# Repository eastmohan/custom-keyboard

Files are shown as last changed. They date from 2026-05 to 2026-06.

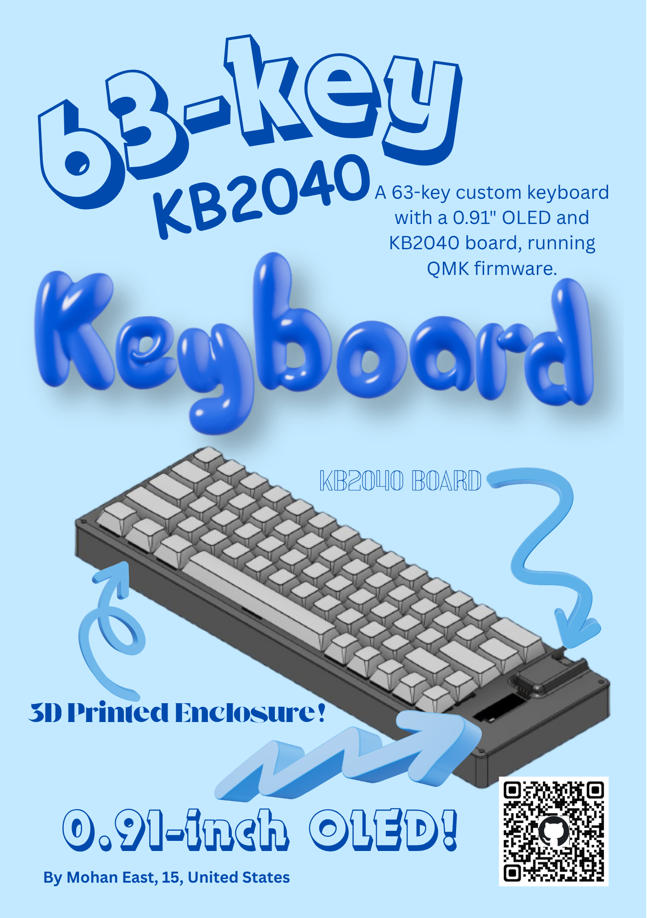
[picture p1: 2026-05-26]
zine_page.png

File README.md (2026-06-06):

# custom-keyboard
**What?** </br>
This is a custom keyboard using KB2040 board. It has 63 keys and a 0.91" OLED. See below for the key assignments. 

**Why?** </br>
I am making this because I prefer using a keyboard to work at home rather than the one built in to my computer. The only keyboard I have is an old, somewhat broken membrane keyboard so I figured I'd try to make a custom mechanical one. I previously made a custom macropad, so I thought this would be a cool next step.

NOTE: You may have noticed that there is no .f3d file in the CAD folder. Instead, there is a .f3z file. They are the same except Fusion360, which I used for the CAD, only gives the option to save as .f3z (not .f3d) when you reference other components. Those referenced components are also included in the CAD folder in the **Premade Files** folder.

**To build this project:**
- Upload gerber and drill files to PCB manufacturer website
- Order PCB and components in the BOM
- Place the switches in the PCB
- **Switches should be placed through the keyboard lid 3D print to the PCB**
- Solder switches
- Place the diodes in the PCB in the correct orientation
- Solder the diodes
- Place the microcontroller
- Solder the microcontroller pin headers to the PCB and to the microcontroller
- Place button and solder
- 3D print case and insert PCB
- Plug microcontroller into computer in boot mode, upload firmware
- Enjoy your new keyboard!

**Schematic**

**PCB**

**Case CAD**

**Key Assignments**
Key Assignments <br>
**BOM**
|Part|Source|Quantity|Cost Each|Total Cost|Link|
|---|---|---|---|---|---|
|Keycaps (Mecha Blue)|AliExpress|1|$9.38|$9.38|[Link](https://www.aliexpress.us/item/3256806811144120.html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)|
|Gateron Milky Yellow Pro 2 Switches|Amazon|1|$16.99|$16.99|[Link](https://www.amazon.com/dp/B0C2CWR4HH)|
|KB2040 Microcontroller|Adafruit|1|$8.95|$8.95|[Link](https://www.adafruit.com/product/5302)|
|USBC to USBA Cable|Amazon|1|$7.99|$7.99|[Link](https://www.amazon.com/Braided-Charging-iPhone-Samsung-Galaxy/dp/B0DPMQ7291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)|
|Diodes|Aliexpress|1|$12.53|$12.53|[Link](https://www.aliexpress.us/item/3256807937287294.html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)|
|0.91" OLED|Aliexpress|1|$2.89|$2.89|[Link](https://www.aliexpress.us/item/3256808615612857.html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)|
|M3 Heatset Insert, OD 4.2mm|Aliexpress|1|$3.60|$3.60|[Link](https://www.aliexpress.us/item/3256803396040989.html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)|
|Stabilizers|Aliexpress|1|$5.92|$5.92|[Link](https://www.aliexpress.us/item/3256801499984864.html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)|
|PCB|JLCPCB|1 (5 pack)|$17.10|$17.10|Use production files in the PCB folder of this repository.|

zine_page

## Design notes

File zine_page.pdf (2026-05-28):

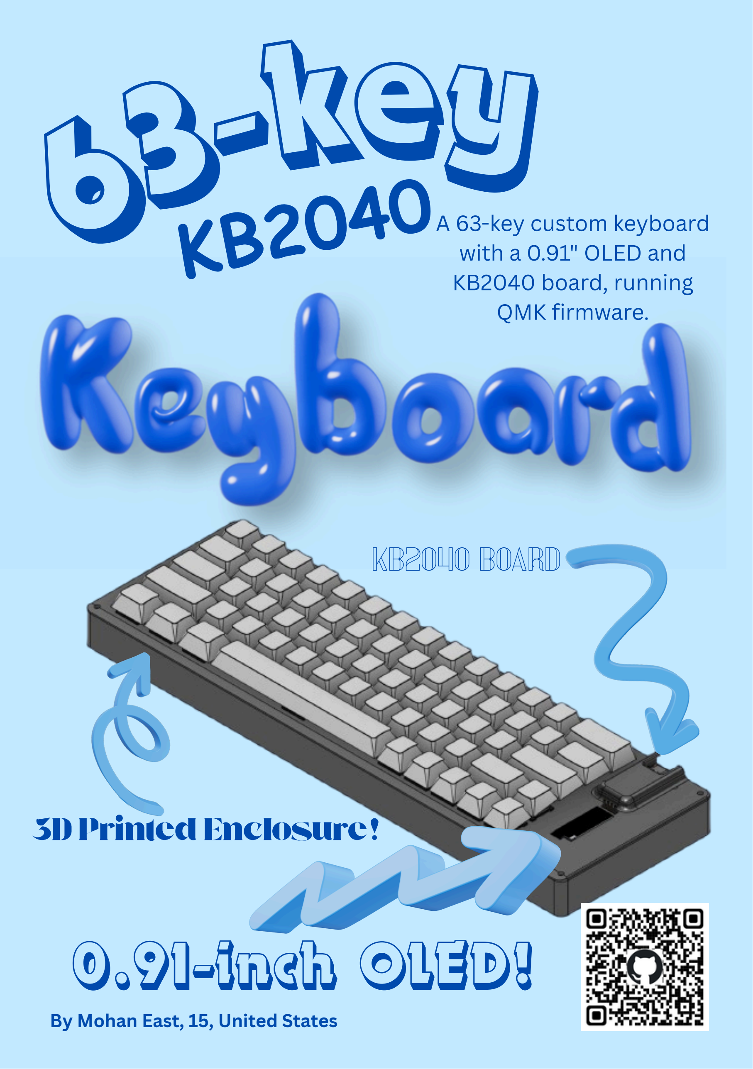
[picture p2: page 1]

# 63-key

KB2040

# 0.91-inch OLED!

KB2040 board

3D Printed Enclosure!

By Mohan East, 15, United States

A 63-key custom keyboard
with a 0.91" OLED and
KB2040 board, running
QMK firmware.

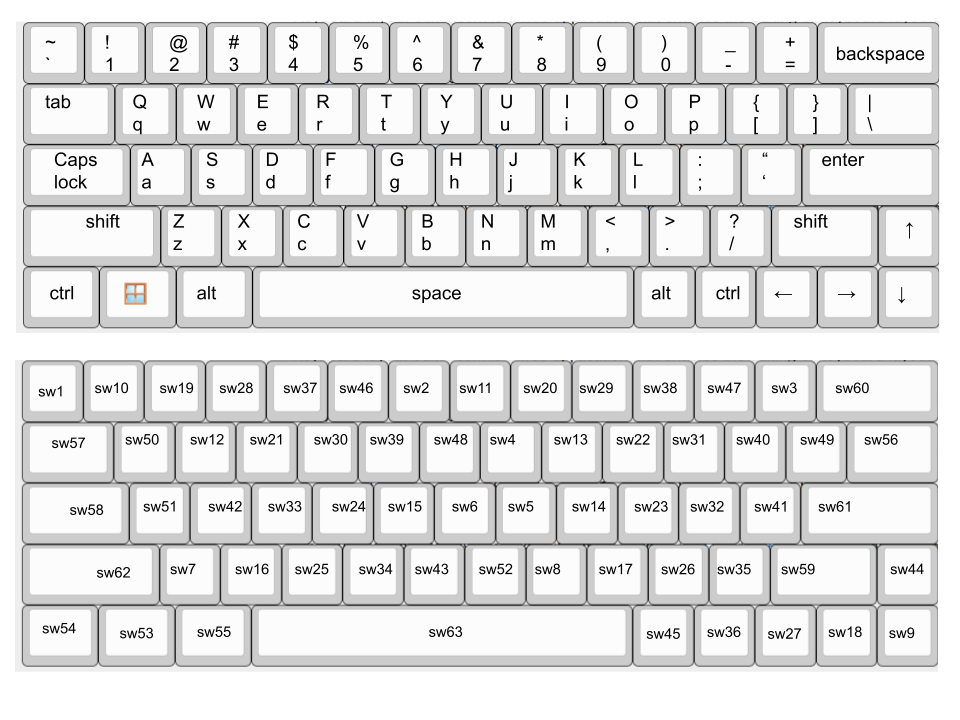
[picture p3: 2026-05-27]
Firmware/Key Assignments.png

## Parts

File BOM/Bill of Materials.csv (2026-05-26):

Part | Source | Quantity | Cost Each | Total Cost | Link
Keycaps | Keychron | 1 | $39.99 | $39.99 | https://www.keychron.com/collections/cherry-profile-double-shot-pbt-keycaps/products/iso-cherry-profile-dye-sub-pbt-full-set-keycap-set-modern-blue
Switches | Kinetic Labs | 4 | $5.04 | $20.16 | https://kineticlabs.com/switches/gateron/gateron-grayish-switches
KB2040 Microcontroller | Adafruit | 1 | $8.95 | $8.95 | https://www.adafruit.com/product/5302
USBC to USBA Cable | Amazon | 1 | $7.99 | $7.99 | https://www.amazon.com/Braided-Charging-iPhone-Samsung-Galaxy/dp/B0DPMQ7291
Diodes | AliExpress | 1 | $12.53 | $12.53 | https://www.aliexpress.us/item/3256807937287294.html?curPageLogUid=lxjO2qs5uYjp
0.91" OLED | AliExpress | 1 | $2.89 | $2.89 | https://www.aliexpress.us/item/3256808615612857.html?curPageLogUid=SMtCSefS9n5l
M3 Heatset Insert, OD 4.2mm | AliExpress | 1 | $3.60 | $3.60 | https://www.aliexpress.us/item/3256803396040989.html?curPageLogUid=5DKc8jmBy4oP
Stabilizers | AliExpress | 1 | $5.92 | $5.92 | https://www.aliexpress.us/item/3256801499984864.html?curPageLogUid=MbHZPmZU1SUn

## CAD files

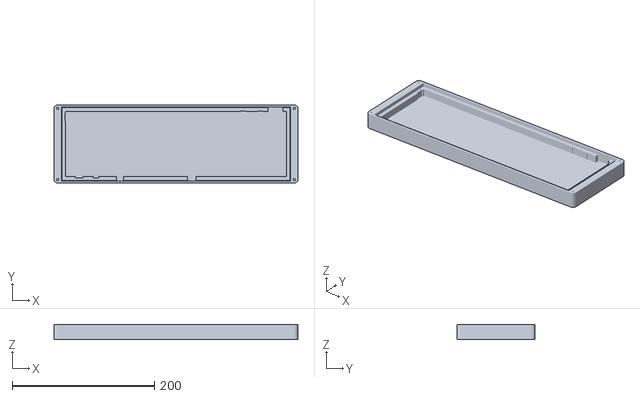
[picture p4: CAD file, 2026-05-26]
CAD/Case+bottom.stl
343.0 x 110.0 x 21.5

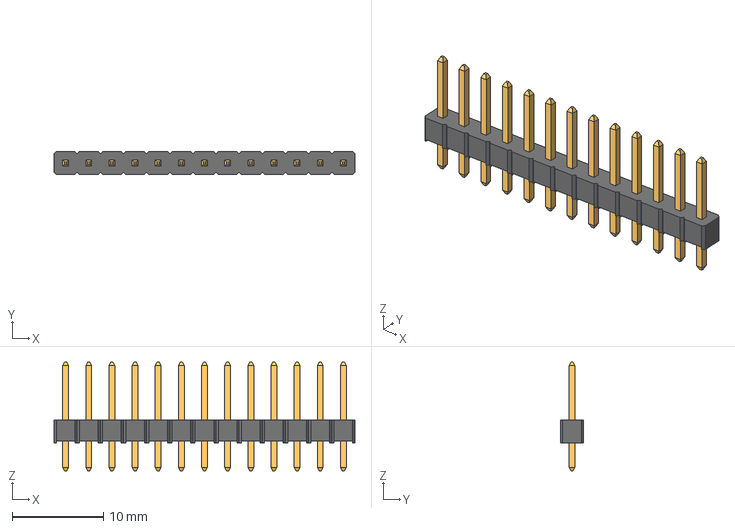
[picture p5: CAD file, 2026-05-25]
CAD/Premade Files/13-Pin Header - Male - 2.54mm.step
33.0 x 2.54 x 11.9 mm

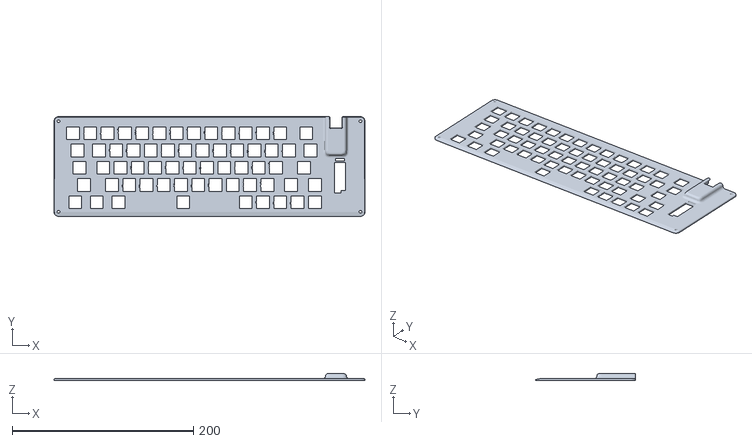
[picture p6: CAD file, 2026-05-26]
CAD/Case+top.stl
343.0 x 110.0 x 7.50

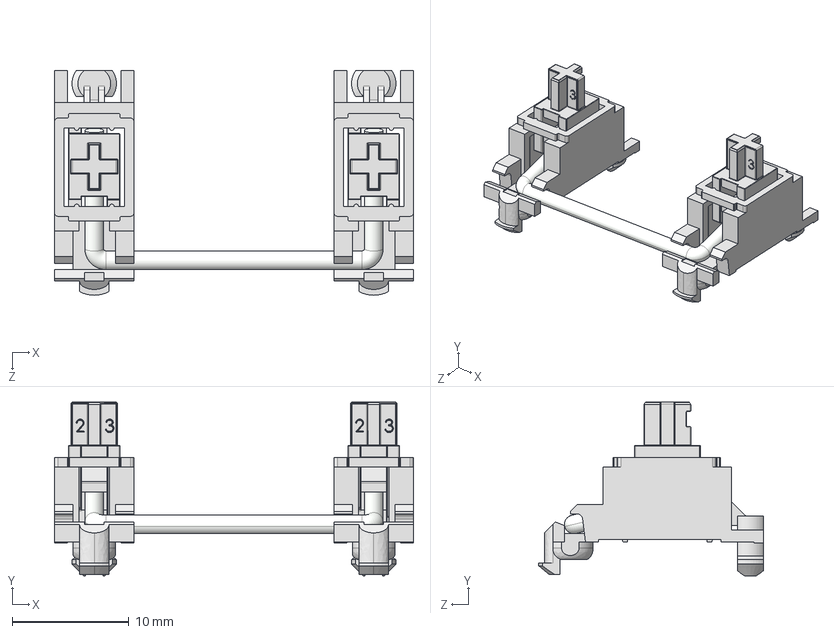
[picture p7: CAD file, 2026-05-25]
CAD/Premade Files/Stabilizer - close.STEP
30.7 x 14.9 x 19.2 mm
mx Stabilizer base 16828 x 2
mx Stabilizer key 16828 x 2
metal stick 16828

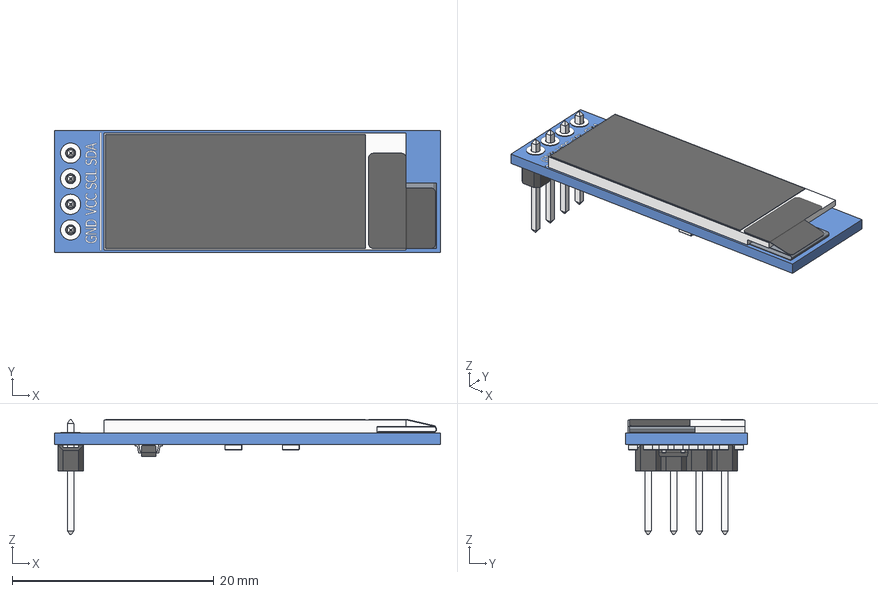
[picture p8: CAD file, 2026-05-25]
CAD/Premade Files/OLED_0.91_128x32.stp
38.3 x 12.1 x 11.5 mm
OLED_0.91_128x32
Pin Header 4 x 1 TH 2.54mm Pitch
RESC-0603 x 13
2SD0601A

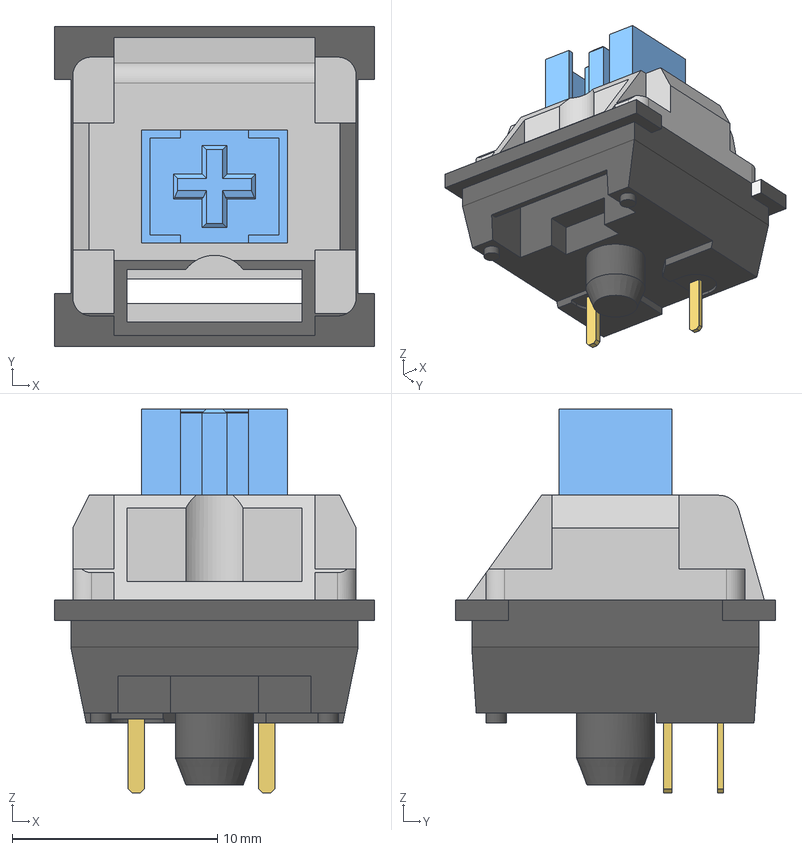
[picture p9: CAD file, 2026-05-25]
CAD/Premade Files/REDragon-MX-ZT02.stp
15.6 x 15.6 x 18.7 mm
Button
Pins

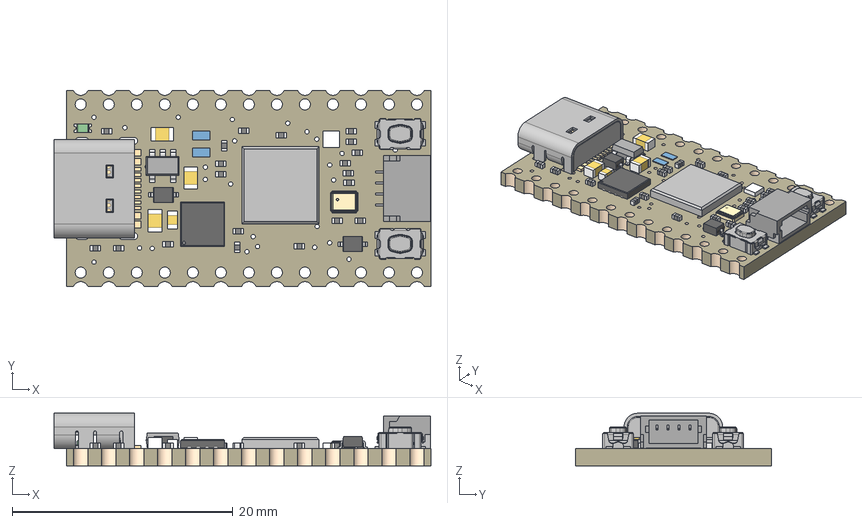
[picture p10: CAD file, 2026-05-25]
CAD/Premade Files/5302 KB2040.step
34.2 x 17.8 x 4.77 mm
Board
10µF x 2
AP2112K-3.3
KMR2 x 2
10K x 20
WS2812B_SK6805_1515
NSR0320 x 2
8MB QSPI Flash
1uF x 2
RP2040_QFN56
12MHZ
1uF_1
USB TYPE C
FUSE
STEMMA_I2C_QTSKINNY
GREEN

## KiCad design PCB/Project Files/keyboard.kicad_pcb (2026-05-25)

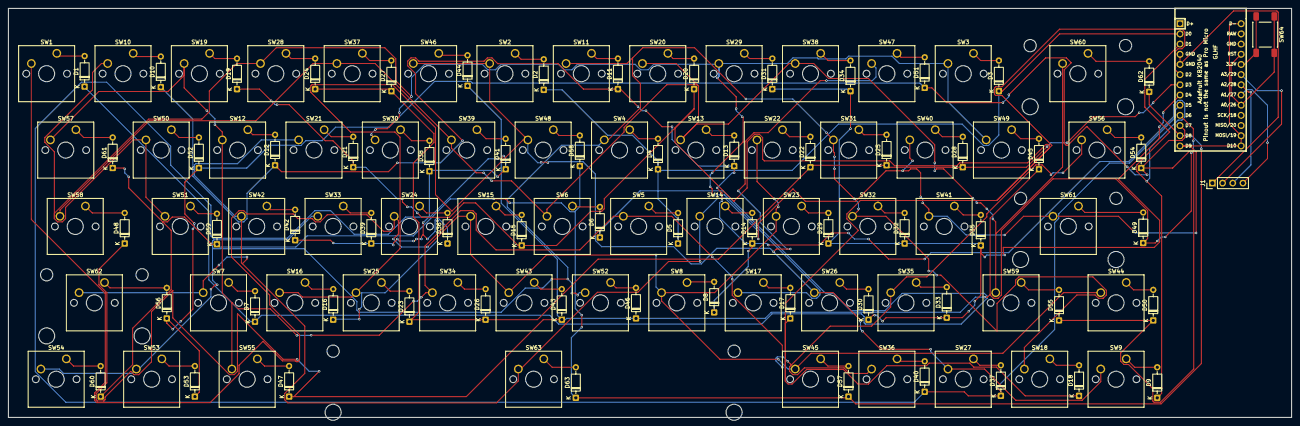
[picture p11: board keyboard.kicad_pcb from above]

Board: 2 copper layers, 320.0 x 102.0 mm, 129 parts (0 on the bottom side), 85 nets.

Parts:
D1, D2, D3, D4, D5, D6, D7, D8, D9, D10, D11, D12, D13, D14, D15, D16, D17, D18, D19, D20, D21, D22, D23, D24, D25, D26, D27, D28, D29, D30, D31, D32, D33, D34, D35, D36, D37, D38, D39, D40, D41, D42, D43, D44, D45, D46, D47, D48, D49, D50, D51, D52, D53, D54, D55, D56, D57, D58, D59, D60, D61, D62, D63: 1N4148; D_DO-35_SOD27_P7.62mm_Horizontal
J1: Conn_01x04; PinHeader_1x04_P2.54mm_Vertical
SW1, SW2, SW3, SW4, SW5, SW6, SW7, SW8, SW9, SW10, SW11, SW12, SW13, SW14, SW15, SW16, SW17, SW18, SW19, SW20, SW21, SW22, SW23, SW24, SW25, SW26, SW27, SW28, SW29, SW30, SW31, SW32, SW33, SW34, SW35, SW36, SW37, SW38, SW39, SW40, SW41, SW42, SW43, SW44, SW45, SW46, SW47, SW48, SW49, SW50, SW51, SW52: SW_Push; SW_Cherry_MX_1.00u_PCB
SW53, SW54, SW55: SW_Push; SW_Cherry_MX_1.25u_PCB
SW56, SW57: SW_Push; SW_Cherry_MX_1.50u_PCB
SW58, SW59: SW_Push; SW_Cherry_MX_1.75u_PCB
SW60: SW_Push; SW_Cherry_MX_2.00u_PCB
SW61, SW62: SW_Push; SW_Cherry_MX_2.25u_PCB
SW63: SW_Push; SW_Cherry_MX_6.25u_PCB
SW64: SW_Push; SW_Push_1P1T_NO_E-Switch_TL3301NxxxxxG
U1: kb2040

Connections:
/COL0: SW7.2, SW14.2, SW21.2, SW40.2, SW41.2, SW42.2, SW61.2, SW62.2, SW63.2, U1.13 (D9)
/COL1: SW6.2, SW13.2, SW20.2, SW37.2, SW38.2, SW39.2, SW58.2, SW59.2, SW60.2
/COL2: SW5.2, SW12.2, SW19.2, SW34.2, SW35.2, SW36.2, SW55.2, SW56.2, SW57.2
/COL3: SW4.2, SW11.2, SW18.2, SW31.2, SW32.2, SW33.2, SW52.2, SW53.2, SW54.2
/COL4: SW3.2, SW10.2, SW17.2, SW28.2, SW29.2, SW30.2, SW49.2, SW50.2, SW51.2
/COL5: SW2.2, SW9.2, SW16.2, SW25.2, SW26.2, SW27.2, SW46.2, SW47.2, SW48.2
/COL6: SW1.2, SW8.2, SW15.2, SW22.2, SW23.2, SW24.2, SW43.2, SW44.2, SW45.2
/ROW0: D1.1 (K), D2.1 (K), D3.1 (K), D4.1 (K), D5.1 (K), D6.1 (K), D7.1 (K), U1.2 (D0)
/ROW1: D8.1 (K), D9.1 (K), D10.1 (K), D11.1 (K), D12.1 (K), D13.1 (K), D14.1 (K), U1.3 (D1)
/ROW2: D15.1 (K), D16.1 (K), D17.1 (K), D18.1 (K), D19.1 (K), D20.1 (K), D21.1 (K), U1.6 (D2)
/ROW3: D22.1 (K), D23.1 (K), D24.1 (K), D25.1 (K), D26.1 (K), D27.1 (K), D28.1 (K), U1.7 (D3)
/ROW4: D29.1 (K), D30.1 (K), D31.1 (K), D32.1 (K), D33.1 (K), D34.1 (K), D35.1 (K), U1.8 (D4)
/ROW5: D36.1 (K), D37.1 (K), D38.1 (K), D39.1 (K), D40.1 (K), D41.1 (K), D42.1 (K), U1.9 (D5)
/ROW6: D43.1 (K), D44.1 (K), D45.1 (K), D46.1 (K), D47.1 (K), D48.1 (K), D49.1 (K), U1.10 (D6)
/ROW7: D50.1 (K), D51.1 (K), D52.1 (K), D53.1 (K), D54.1 (K), D55.1 (K), D56.1 (K), U1.11 (D7)
/ROW8: D57.1 (K), D58.1 (K), D59.1 (K), D60.1 (K), D61.1 (K), D62.1 (K), D63.1 (K), U1.12 (D8)
/SCL: J1.3, U1.19 (A3/29)
/SDA: J1.4, U1.20 (A2/28)
/VCC: J1.2, U1.18 (3.3v)
GND: J1.1, U1.4 (GND), U1.5 (GND)
unnamed: D1.2 (A), SW1.1
unnamed: D2.2 (A), SW2.1
unnamed: D3.2 (A), SW3.1
unnamed: D4.2 (A), SW4.1
unnamed: D5.2 (A), SW5.1
unnamed: D6.2 (A), SW6.1
unnamed: D7.2 (A), SW7.1
unnamed: D8.2 (A), SW8.1
unnamed: D9.2 (A), SW9.1
unnamed: D10.2 (A), SW10.1
unnamed: D11.2 (A), SW11.1
unnamed: D12.2 (A), SW12.1
unnamed: D13.2 (A), SW13.1
unnamed: D14.2 (A), SW14.1
unnamed: D15.2 (A), SW15.1
unnamed: D16.2 (A), SW16.1
unnamed: D17.2 (A), SW17.1
unnamed: D18.2 (A), SW18.1
unnamed: D19.2 (A), SW19.1
unnamed: D20.2 (A), SW20.1
unnamed: D21.2 (A), SW21.1
unnamed: D22.2 (A), SW22.1
unnamed: D23.2 (A), SW25.1
unnamed: D24.2 (A), SW28.1
unnamed: D25.2 (A), SW31.1
unnamed: D26.2 (A), SW34.1
unnamed: D27.2 (A), SW37.1
unnamed: D28.2 (A), SW40.1
unnamed: D29.2 (A), SW23.1
unnamed: D30.2 (A), SW26.1
unnamed: D31.2 (A), SW29.1
unnamed: D32.2 (A), SW32.1
unnamed: D33.2 (A), SW35.1
unnamed: D34.2 (A), SW38.1
unnamed: D35.2 (A), SW41.1
unnamed: D36.2 (A), SW24.1
unnamed: D37.2 (A), SW27.1
unnamed: D38.2 (A), SW30.1
unnamed: D39.2 (A), SW33.1
unnamed: D40.2 (A), SW36.1
unnamed: D41.2 (A), SW39.1
unnamed: D42.2 (A), SW42.1
unnamed: D43.2 (A), SW43.1
unnamed: D44.2 (A), SW46.1
unnamed: D45.2 (A), SW49.1
unnamed: D46.2 (A), SW52.1
unnamed: D47.2 (A), SW55.1
unnamed: D48.2 (A), SW58.1
unnamed: D49.2 (A), SW61.1
unnamed: D50.2 (A), SW44.1
unnamed: D51.2 (A), SW47.1
unnamed: D52.2 (A), SW50.1
unnamed: D53.2 (A), SW53.1
unnamed: D54.2 (A), SW56.1
unnamed: D55.2 (A), SW59.1
unnamed: D56.2 (A), SW62.1
unnamed: D57.2 (A), SW45.1
unnamed: D58.2 (A), SW48.1
unnamed: D59.2 (A), SW51.1
unnamed: D60.2 (A), SW54.1
unnamed: D61.2 (A), SW57.1
unnamed: D62.2 (A), SW60.1
unnamed: D63.2 (A), SW63.1
unnamed: SW64.1, U1.16 (GND)
unnamed: SW64.2, U1.17 (RESET)

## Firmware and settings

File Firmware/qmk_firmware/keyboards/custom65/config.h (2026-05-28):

#pragma once
#define MATRIX_ROWS 9
#define MATRIX_COLS 7
#define MATRIX_ROW_PINS {GP0, GP1, GP2, GP3, GP4, GP5, GP6, GP7, GP8 }
#define MATRIX_COL_PINS {GP9, GP10, GP19, GP20, GP18, GP26, GP27 }

#define DIODE_DIRECTION COL2ROW

#define DEBOUNCE 5
#define USB_SUSPEND_WAKEUP_DELAY 0
#define I2C_DRIVER I2CD1
#define OLED_DISPLAY_128x32
#define OLED_TIMEOUT 30000

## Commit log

2026-05-25 PCB Files
2026-05-25 CAD and PCB Files
    [13-Pin Header - Male - 2.54mm.step, 5302 KB2040.step, OLED_0.91_128x32.stp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]
2026-05-25 Added CAD and PCB Files
2026-05-26 Added case CAD
    [Case+bottom.stl, Case+top.stl]
2026-05-26 Updated CAD to reflect new PCB version
2026-05-26 Added BOM .csv
    [Bill of Materials.csv]
2026-05-26 Added PCB Production Files
    [keyboard-B_Cu.gbr, keyboard-B_Mask.gbr, keyboard-B_Paste.gbr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]
2026-05-27 Add Key Assignments
    [Key Assignments.csv]
2026-05-28 Updated CAD
2026-05-28 Move BOM
    [Bill of Materials.csv]
